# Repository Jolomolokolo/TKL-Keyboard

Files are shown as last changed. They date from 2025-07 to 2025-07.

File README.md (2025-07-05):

# TKL Keyboard – Custom Tenkeyless Mechanical Keyboard with Integrated RP2040

This project is a custom-designed TKL (Tenkeyless) mechanical keyboard with an ISO DE/QWERTZ layout. It features a fully hand-routed PCB with an onboard RP2040 microcontroller, integrated flash memory, reset and boot buttons, and support for hot-swap sockets.

---

## Project Overview

### Keyboard Overview  
This is an overview of the complete TKL keyboard project, including schematic, PCB, and case layout:

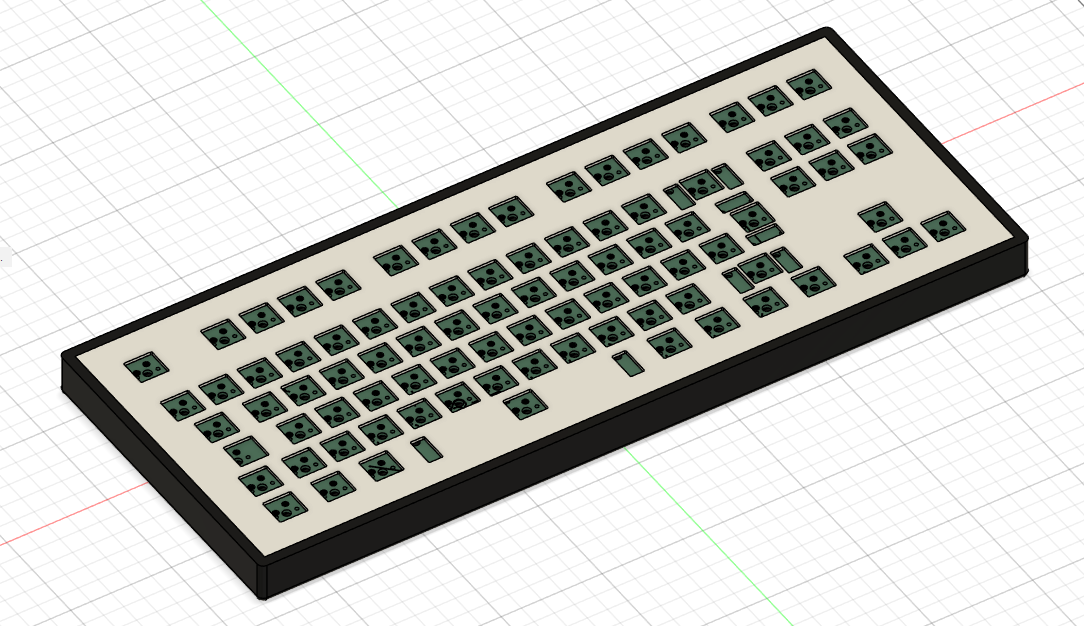
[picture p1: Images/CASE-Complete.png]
Keyboard Overview


---

### Schematic  
The keyboard uses a row-column matrix with diodes to prevent ghosting. The RP2040 is directly mounted on the PCB along with a crystal, power regulation, ESD protection, and SPI flash for firmware storage.

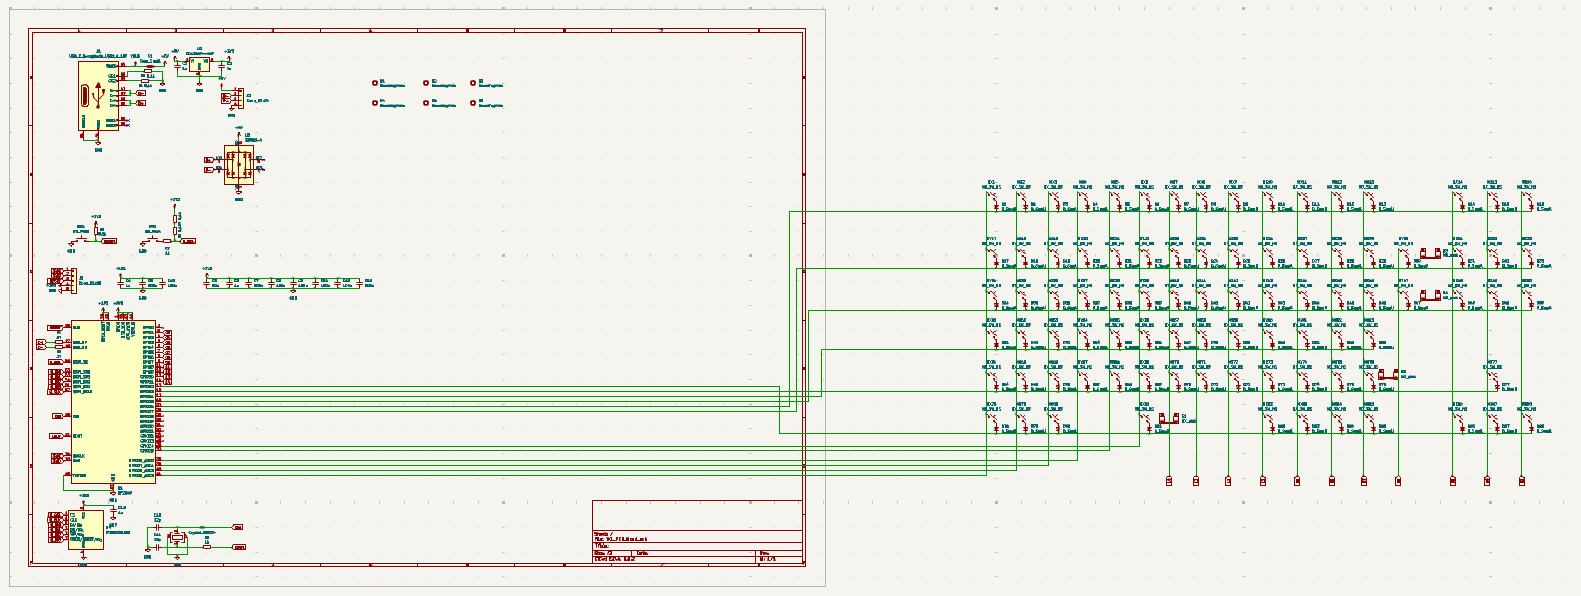
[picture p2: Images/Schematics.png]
Schematic


---

### PCB Layout  
The PCB is fully hand-routed and includes:

- RP2040 with external flash memory  
- USB-C port for programming and power  
- Boot and reset buttons  
- Crystal oscillator  
- Fuse for protection  
- Support for hot-swap switch sockets  
- ISO DE/QWERTZ-compliant layout  

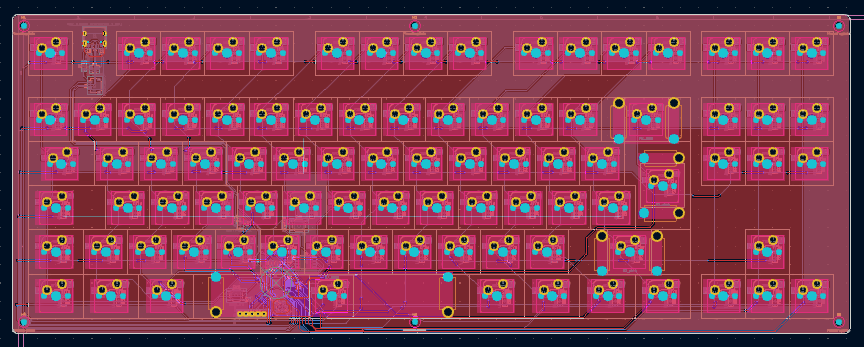
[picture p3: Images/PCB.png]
PCB Layout


---

### Case & Assembly  
The case uses standoffs, heated inserts, and screws to mount the PCB securely. Cutout for USB-C.
Compatible with standard MX keycaps and Cherry stabilizers.

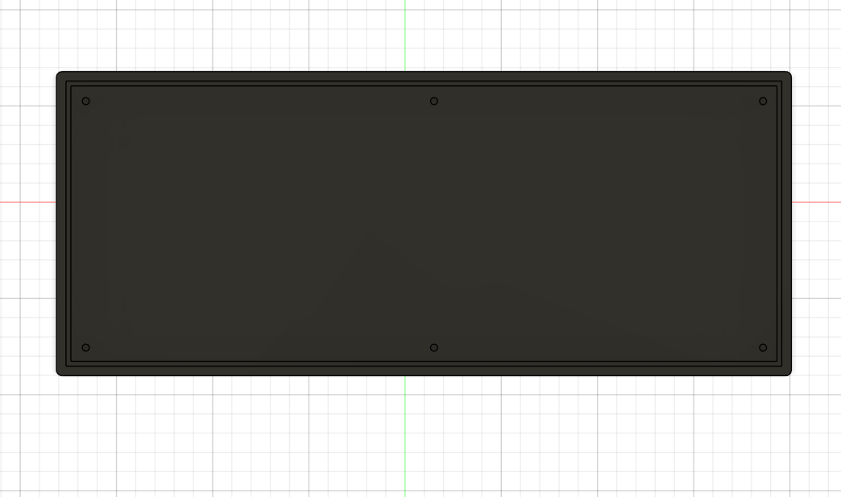
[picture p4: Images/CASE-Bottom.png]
Case Bottom with space for heated inserts

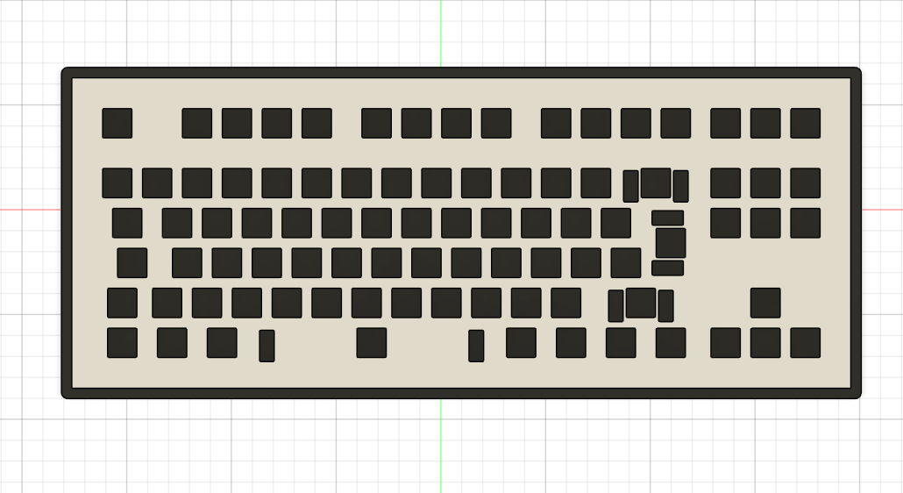
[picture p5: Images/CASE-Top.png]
Case


---

## Bill of Materials (BOM)

| Qty | Component | Value / Description | Footprint / Type |Price |
|-----|---|---|---|---|
| 8 | Capacitor | 100n | C_0402 |\/ |
| 5 | Capacitor | 1u | C_0402 |\/ |
| 2 | Capacitor | 22p | C_0402 |\/ |
| 1 | Capacitor | 10u | C_0603 |\/ |
| 5 | Resistor | 5.1k | R_0402 |\/ |
| 2 | Resistor | 27k | R_0402 |\/ |
| 2 | Resistor | 1k | R_0402 |\/ |
| 88  | Diodes | 1N4148 or equivalent (Ghosting Prevention) | SOD-123 |\/ |
| 1 | Microcontroller | RP2040 | QFN-56 |\/ |
| 1 | Voltage Regulator | XC6206PxxxMR | SOT-23-3 |\/ |
| 1 | ESD Protection | SRV05-4 | SOT-23-6 |\/ |
| 1 | Flash Memory | W25Q128JVS | SOIC-8 |\/ |
| 1 | Crystal | 12MHz / GND24 | SMD 3225-4Pin |\/ |
| 1 | Fuse | For USB protection | 1206 |\/ |
| 2 | Push Button | Reset / Boot | TL3342 |$128,97 |
| 88  | Hot-swap Sockets | MX-compatible | CPG151101S11 |$6,28 | 
| 4 | Stabilizers | 6.25u / 2.75u / 2u / ISO | Cherry MX |$11,77 |
| 1 | USB Port | USB-C 2.0 | 16P Receptacle |$2,01 |
| 1 | Debug Header | 4-pin JST | JST-SH 1.0mm |\/ |
| 1 | Debug Header | 5-pin Header | 2.54mm Vertical |$3,36 |
| 88  | Switches | Cherry MX or clone | MX-compatible |$61,24 |
| 88  | Keycaps | ISO DE Layout | Cherry Profile |$16,71 |
| 6 | Standoffs | 6×6mm M2.5 | Female-Male |$1,17 |
| 6 | Screws | M2.5×6mm | Steel |$1,78 |
| 6 | Heated Inserts | M2.5×6mm | Brass |$7,93 |
| 1 | USB Cable | USB-A to USB-C | — |- |
| | | | |Total: $241,22|

* "\/" means: Price is from a package/some parts are bought together and the price is under the arrow pointing down!
* Price is more than $150: I saw a $75 coupon for JLCPCB which would make the price a bit lower and the rest I would pay from my money!
---

## Firmware

The firmware is based on [KMK Firmware](https://github.com/KMKfw/kmk_firmware), a powerful Python-based keyboard firmware running on CircuitPython.

- Full matrix mapping (ISO DE layout)  
- Boot/reset control  
- Flash via USB, no external programmer required

Configuration is managed via `code.py` and `keymap.py`.

- Multi Layer Keyboard will be added!

---

## Future Improvements
 
- Add rotary encoder or OLED display  
- Bluetooth support (via BLE module)  
- Add underglow LED layer

---

## License

This project is open-source under the MIT License.

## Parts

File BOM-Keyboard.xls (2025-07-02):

Description | Category | References | Value | Footprint | Quantity | Total Quantity | Links | Price
Capacitor for USB and RP | PCB | C5, C7, C8, C9, C13, C14, C15, C16 | 100n | C_0402_1005Metric | 8 | 8 | PCB – JLCPCB | 128,97 Dollar
 |  | C1, C2, C4, C6, C12 | 1u | C_0402_1005Metric | 5 | 5
 |  | C10, C11 | 22p | C_0402_1005Metric | 2 | 2
 |  | C3 | 10u | C_0603_1608Metric | 1 | 1
Resistor for USB and RP |  | R1, R2, R3, R8, R9 | 5,1k | R_0402_1005Metric | 5 | 5
 |  | R4, R5 | 27k | R_0402_1005Metric | 2 | 2
 |  | R6, R7 | 1k | R_0402_1005Metric | 2 | 2
Diodes for Ghosting Prevention |  | D1, D2, D3, D4, D5, D6, D7, D8, D9, D10, D11, D12, D13, D14, D15, D16, D17, D18, D19, D20, D21, D22, D23, D24, D25, D26, D27, D28, D29, D30, D31, D32, D33, D34, D35, D36, D37, D38, D39, D40, D41, D42, D43, D44, D45, D46, D47, D48, D49, D50, D51, D52, D53, D54, D55, D56, D57, D58, D59, D60, D61, D62, D63, D64, D65, D66, D67, D68, D69, D70, D71, D72, D73, D74, D75, D76, D77, D78, D79, D80, D81, D82, D83, D84, D85, D86, D87, D88 | D_Small | D_SOD-123 | 88 | 88
Micro Controller |  | U1 | RP2040 | QFN-56-1EP_7x7mm_P0.4mm_EP3.2x3.2mm | 1 | 1
MISC: Flash Memory and stuff like that |  | U2 | XC6206PxxxMR | SOT-23-3 | 1 | 1
 |  | U3 | SRV05-4 | SOT-23-6-routable | 1 | 1
 |  | U4 | W25Q128JVS | SOIC-8_5.3x5.3mm_P1.27mm | 1 | 1
Crystal for Timing |  | Y1 | Crystal_GND24 | Crystal_SMD_3225-4Pin_3.2x2.5mm | 1 | 1
Fuse for safety |  | F1 | Fuse_Small | Fuse_1206_3216Metric | 1 | 1
Push Buttons for Reset and Flash-Reset |  | SW1, SW2 | SW_Push | SW_SPST_TL3342 | 2 | 2
Kalith Hot-Swap mountings |  | MX1, MX2, MX3, MX4, MX5, MX6, MX7, MX8, MX9, MX10, MX11, MX12, MX13, MX14, MX15, MX16, MX17, MX18, MX19, MX20, MX21, MX22, MX23, MX24, MX25, MX26, MX27, MX28, MX29, MX30, MX31, MX32, MX33, MX35, MX36, MX37, MX38, MX39, MX40, MX41, MX42, MX43, MX44, MX45, MX46, MX47, MX48, MX49, MX50, MX52, MX53, MX54, MX55, MX56, MX57, MX58, MX59, MX60, MX61, MX62, MX63, MX65, MX66, MX67, MX68, MX69, MX70, MX71, MX72, MX73, MX74, MX75, MX76, MX77, MX81, MX86, MX87, MX88 | MX_SW_HS | SW_MX_HS_CPG151101S11_1u | 78 | 88 | https://www.aliexpress.com/ssr/300000512/BundleDeals2?productIds=1005008078624472:12000043571615166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 | 5.33 €
 |  | MX64, MX78, MX79, MX80, MX82, MX83, MX84, MX85 | MX_SW_HS | SW_MX_HS_CPG151101S11_1.25u | 8
 |  | MX34 | MX_SW_HS | SW_MX_HS_CPG151101S11_1.5u | 1
 |  | MX51 | MX_SW_HS | SW_MX_HS_CPG151101S11_1.75u_STP_1.25 | 1
Stabilizer for bigger Keys |  | S1 | MX_stab | STAB_MX_P_6.25u | 1 | 1 – SET | https://www.computerxtreme.de/Glorious-Stabilizers-V2?gh=2 | 9.99 €
 |  | S2 | MX_stab | STAB_MX_P_2.75u | 1
 |  | S3 | MX_stab | STAB_MX_P_2u | 1
 |  | S4 | MX_stab | STAB_MX_P_ISO-ROT | 1
USB-C 2.0 Port |  | J1 | USB_C_Receptacle_USB2.0_16P | USB_C_Receptacle_HRO_TYPE-C-31-M-12 | 1 | 1 | https://de.aliexpress.com/item/1005003285152827.html | 1.71 €
Pin Header for Debug |  | J2 | Conn_01x04 | JST_SH_SM04B-SRSS-TB_1x04-1MP_P1.00mm_Horizontal | 1 | 1 | https://de.aliexpress.com/item/1005006498660940.html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 | 2.85 €
 |  | J3 | Conn_01x05 | PinHeader_1x05_P2.54mm_Vertical | 1 | 1
Keys for Keyboard | Keys |  | Cherry MX Keys | Cherry MX Keys | 88 | 88 | https://www.reichelt.de/de/de/shop/produkt/cherry_mx_red_rgb_-_tastenmodul-401645 | 52.00 €
Keycaps for Keyboard |  |  | Cherry MX Keycaps | Cherry MX Keycaps, different sizes | 88 | 1-SET | https://de.aliexpress.com/item/4001297074837.html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 | 14.19 €
Standoffs for PCB-Mounting | Case/Mounting |  | Standoff 6mmx6mm – M2,5 | Standoffs 6mmx6mm – female-male | 6 | 6 | https://de.aliexpress.com/item/1005006202979514.html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 | 0.99 €
Screws for PCB-Mounting |  |  | Screws M2,5mmx6mm | Screws M2,5mmx6mm | 6 | 6 | https://de.aliexpress.com/item/1005002357962115.html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 | 1.51 €
Heated inserts for PCB-Mounting |  |  | Heated inserts for M2,5x6mm | M2,5mmxL6mmxD3,5mm | 6 | 6 | https://de.aliexpress.com/item/1005007830491580.html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 | 6.73 € | 95.30 €
Programming | Others |  | USB-A to USB-C | USB-A to USB-C | 1 | 1
 |  |  |  |  |  |  |  | Total in USD
 |  |  |  |  |  |  |  | PCB | $128.97
 |  |  |  |  |  |  |  | Parts | $112.47
 |  |  |  |  |  |  |  |  | $241.44

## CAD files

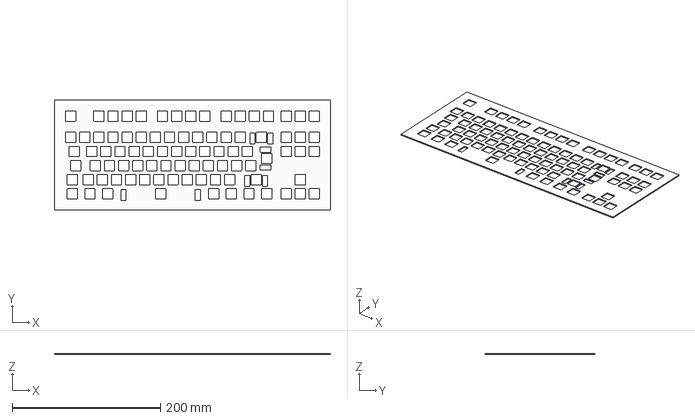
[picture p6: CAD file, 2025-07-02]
CAD/TKL-Keyboard-Top.step
371.9 x 148.1 x 1.50 mm

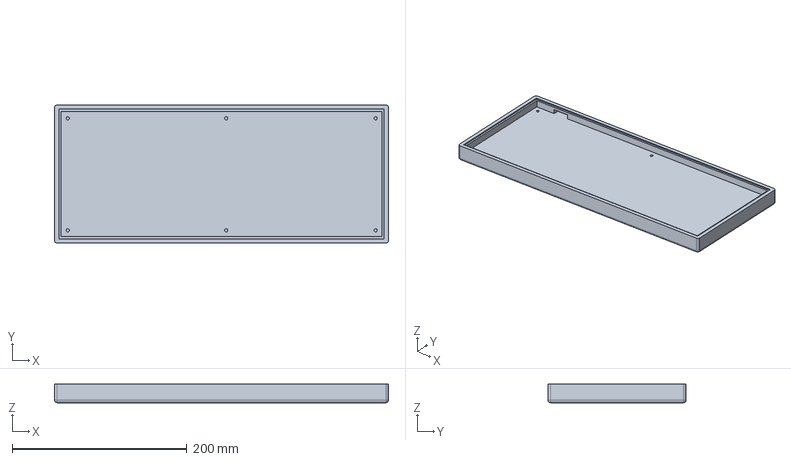
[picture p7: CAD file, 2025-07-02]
CAD/TKL-Keyboard-Bottom.step
381.9 x 158.1 x 21.2 mm

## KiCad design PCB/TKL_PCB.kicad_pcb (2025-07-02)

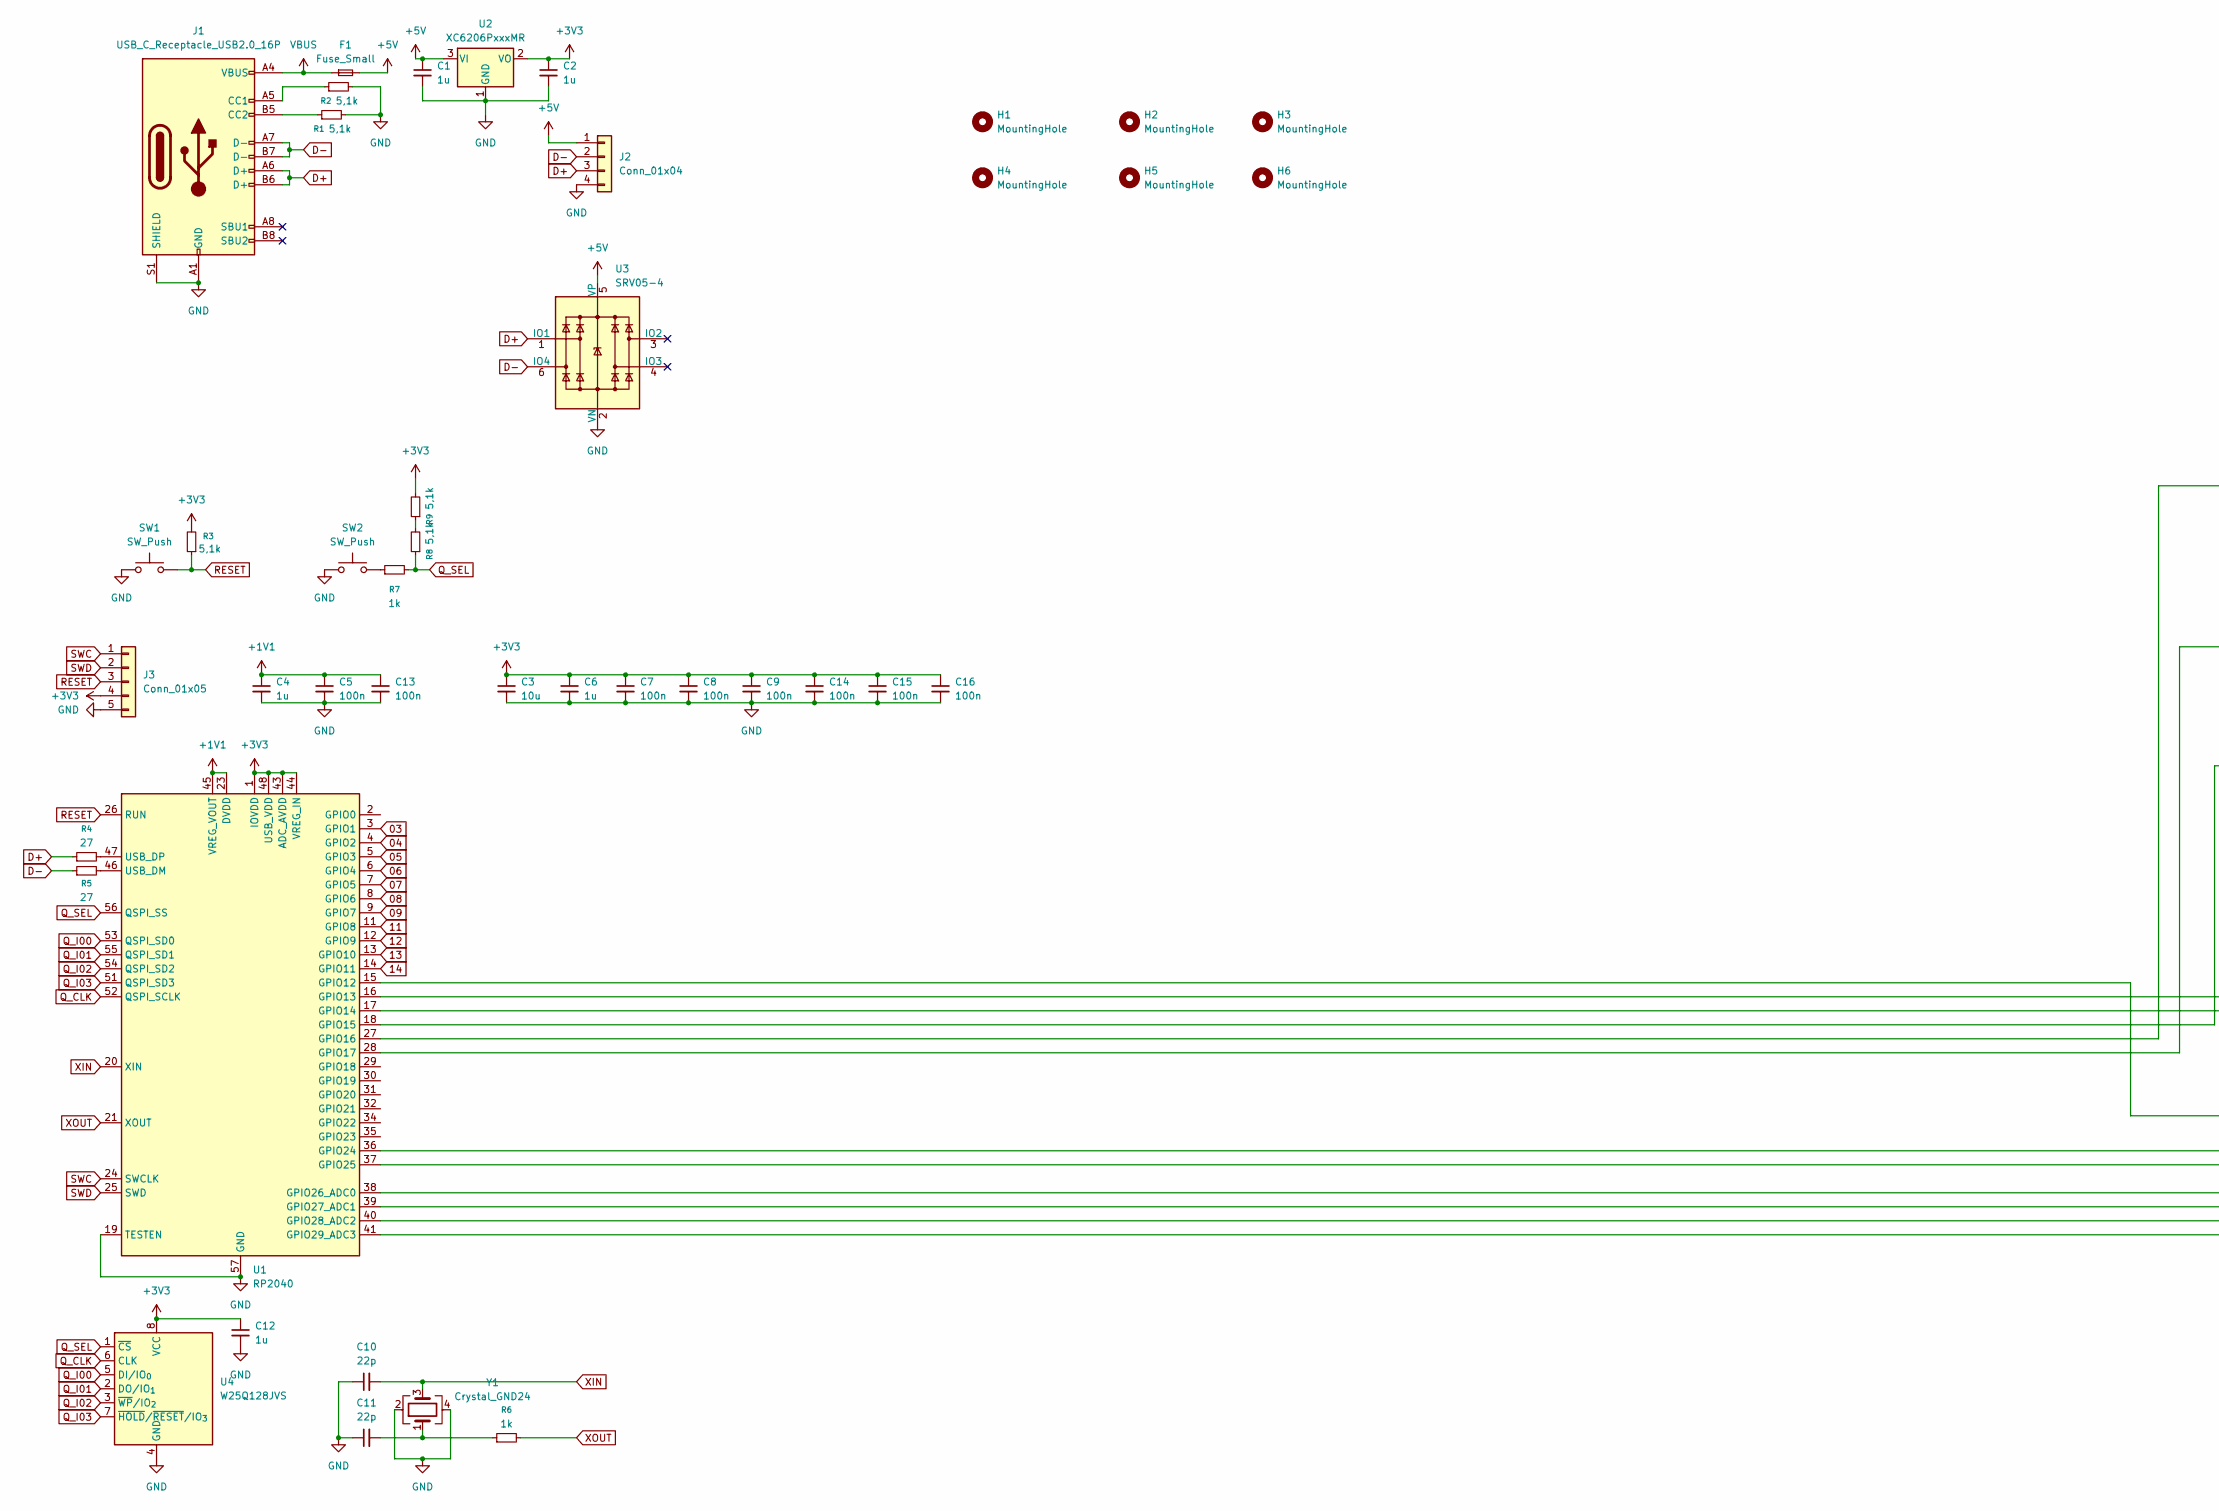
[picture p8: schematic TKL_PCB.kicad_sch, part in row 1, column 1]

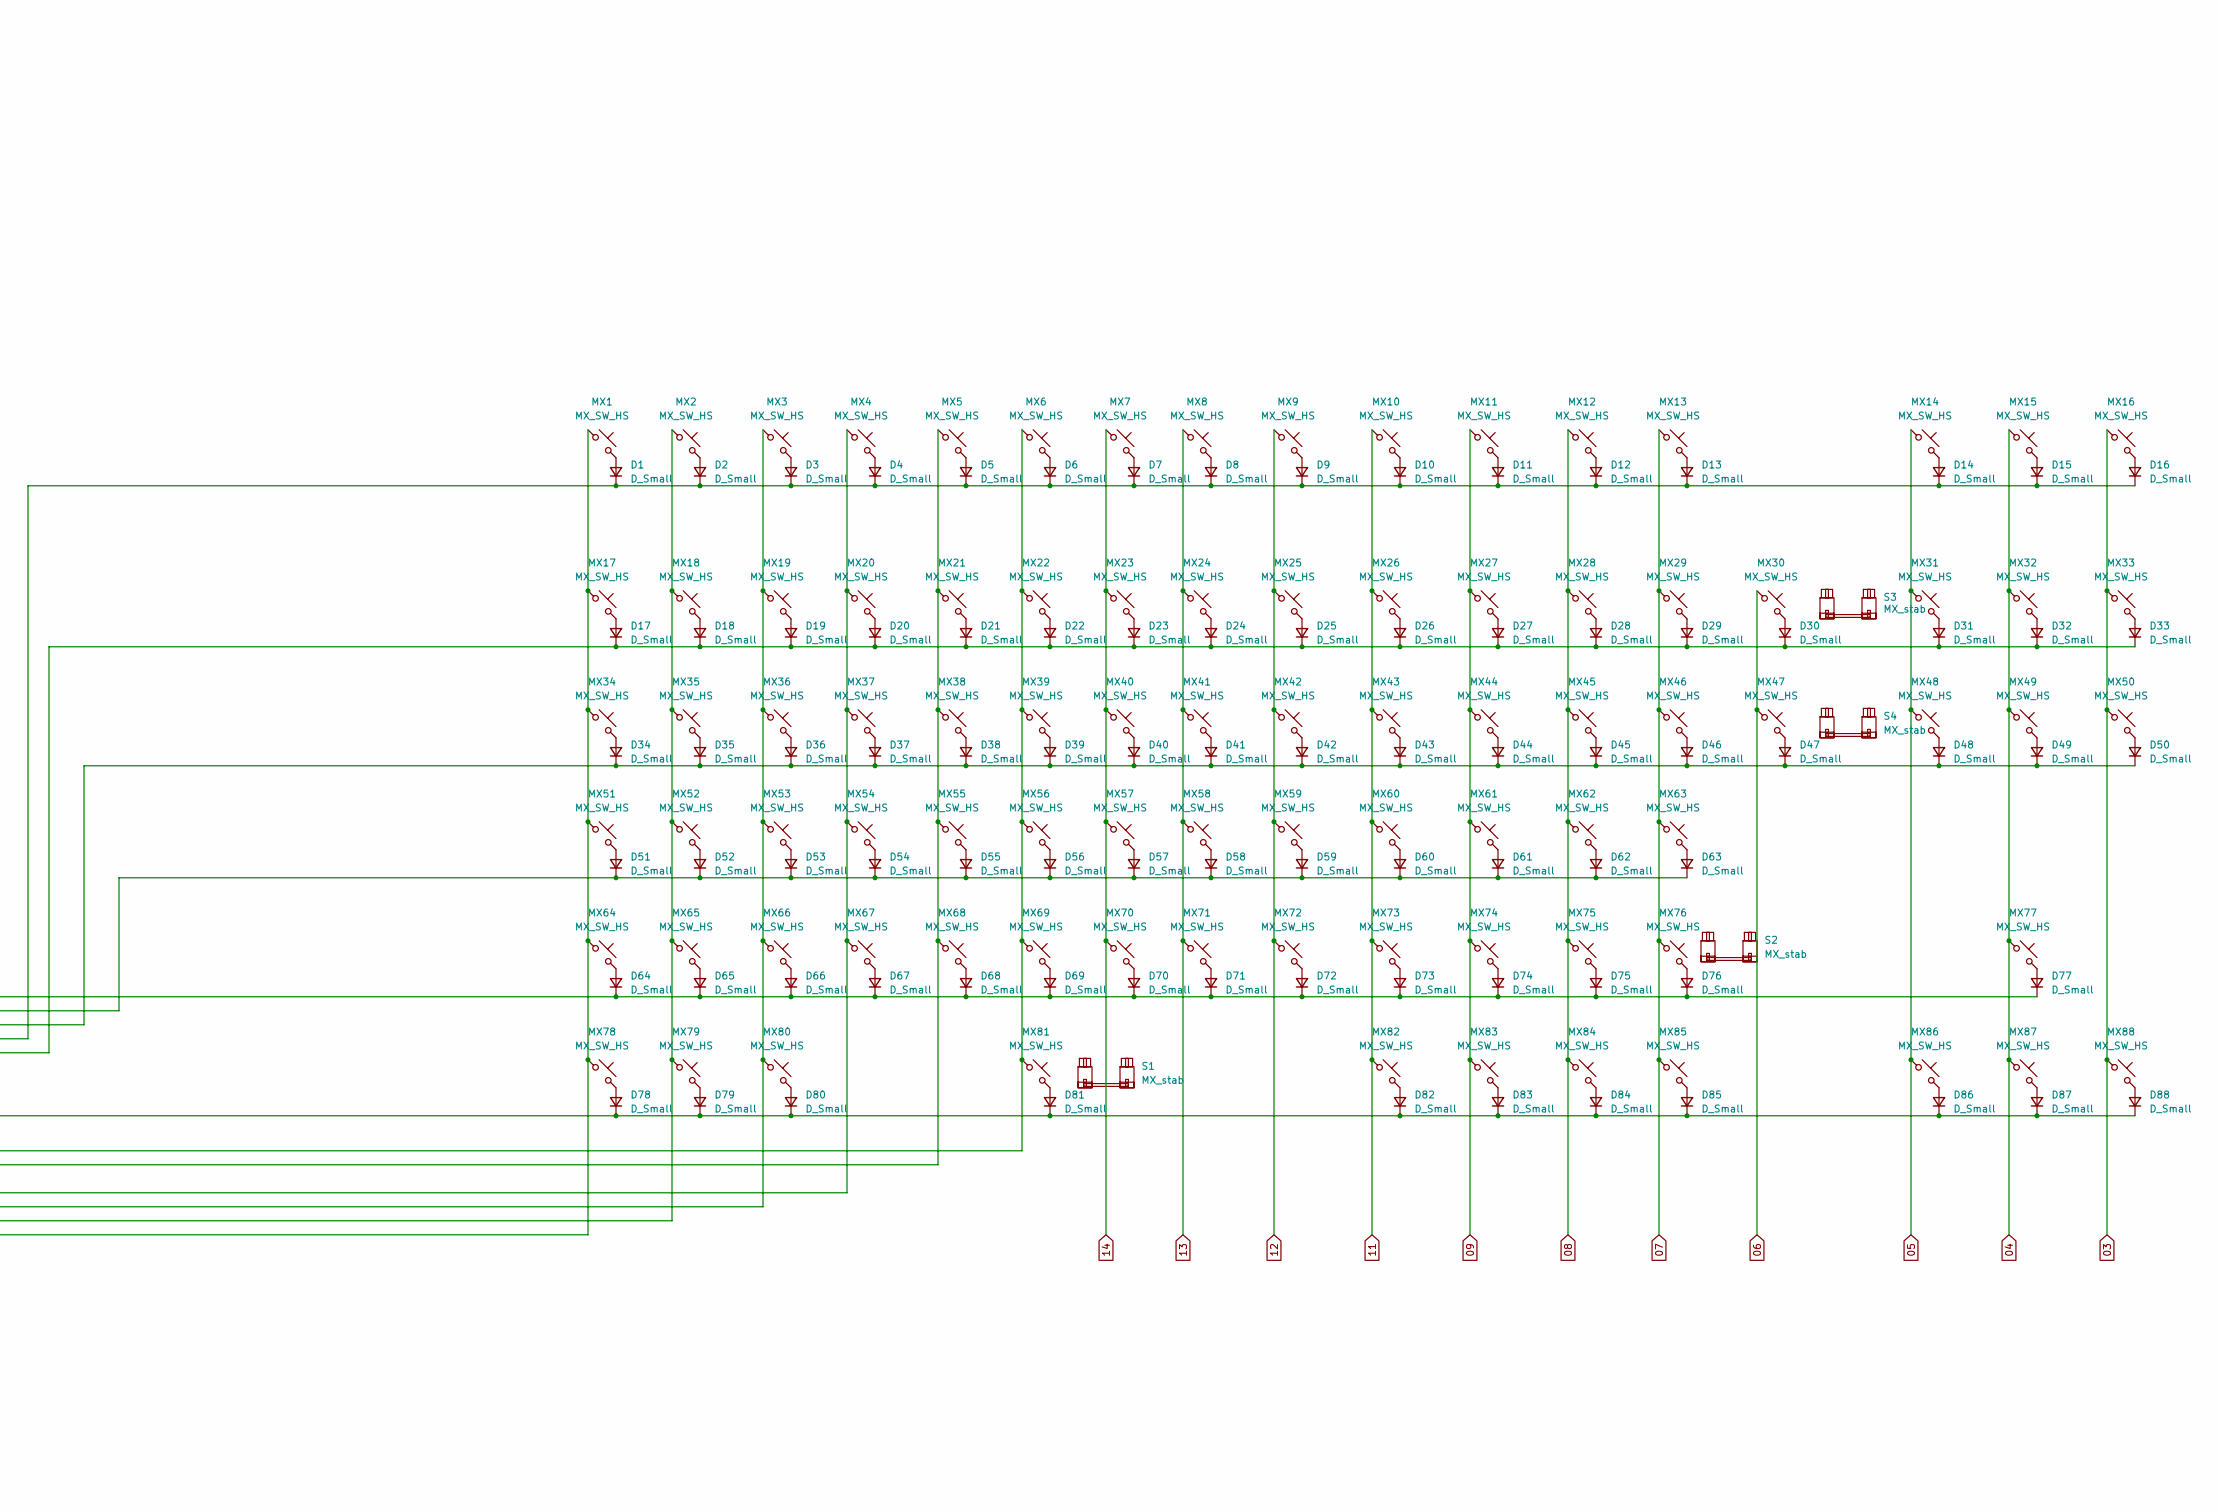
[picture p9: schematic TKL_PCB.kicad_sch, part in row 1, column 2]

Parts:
C1, C2, C4, C6, C12: 1u; C_0402_1005Metric
C3: 10u; C_0603_1608Metric
C5, C7, C8, C9, C13, C14, C15, C16: 100n; C_0402_1005Metric
C10, C11: 22p; C_0402_1005Metric
D1, D2, D3, D4, D5, D6, D7, D8, D9, D10, D11, D12, D13, D14, D15, D16, D17, D18, D19, D20, D21, D22, D23, D24, D25, D26, D27, D28, D29, D30, D31, D32, D33, D34, D35, D36, D37, D38, D39, D40, D41, D42, D43, D44, D45, D46, D47, D48, D49, D50, D51, D52, D53, D54, D55, D56, D57, D58, D59, D60, D61, D62, D63, D64, D65, D66, D67, D68, D69, D70, D71, D72, D73, D74, D75, D76, D77, D78, D79, D80, D81, D82, D83, D84, D85, D86, D87, D88: D_Small; D_SOD-123
F1: Fuse_Small; Fuse_1206_3216Metric
H1, H2, H3, H4, H5, H6: MountingHole; MountingHole_2.5mm
J1: USB_C_Receptacle_USB2.0_16P; USB_C_Receptacle_HRO_TYPE-C-31-M-12
J2: Conn_01x04; JST_SH_SM04B-SRSS-TB_1x04-1MP_P1.00mm_Horizontal
J3: Conn_01x05; PinHeader_1x05_P2.54mm_Vertical
MX1, MX2, MX3, MX4, MX5, MX6, MX7, MX8, MX9, MX10, MX11, MX12, MX13, MX14, MX15, MX16, MX17, MX18, MX19, MX20, MX21, MX22, MX23, MX24, MX25, MX26, MX27, MX28, MX29, MX30, MX31, MX32, MX33, MX35, MX36, MX37, MX38, MX39, MX40, MX41, MX42, MX43, MX44, MX45, MX46, MX47, MX48, MX49, MX50, MX52, MX53, MX54, MX55, MX56, MX57, MX58, MX59, MX60, MX61, MX62, MX63, MX65, MX66, MX67, MX68, MX69, MX70, MX71, MX72, MX73, MX74, MX75, MX76, MX77, MX81, MX86, MX87, MX88: MX_SW_HS; SW_MX_HS_CPG151101S11_1u
MX34: MX_SW_HS; SW_MX_HS_CPG151101S11_1.5u
MX51: MX_SW_HS; SW_MX_HS_CPG151101S11_1.75u_STP_1.25
MX64, MX78, MX79, MX80, MX82, MX83, MX84, MX85: MX_SW_HS; SW_MX_HS_CPG151101S11_1.25u
R1, R2, R3, R8, R9: 5,1k; R_0402_1005Metric
R4, R5: 27; R_0402_1005Metric
R6, R7: 1k; R_0402_1005Metric
S1: MX_stab; STAB_MX_P_6.25u
S2: MX_stab; STAB_MX_P_2.75u
S3: MX_stab; STAB_MX_P_2u
S4: MX_stab; STAB_MX_P_ISO-ROT
SW1, SW2: SW_Push; SW_SPST_TL3342
U1: RP2040; QFN-56-1EP_7x7mm_P0.4mm_EP3.2x3.2mm
U2: XC6206PxxxMR; SOT-23-3
U3: SRV05-4; SOT-23-6-routable
U4: W25Q128JVS; SOIC-8_5.3x5.3mm_P1.27mm
Y1: Crystal_GND24; Crystal_SMD_3225-4Pin_3.2x2.5mm

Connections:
03: MX16.1, MX33.1, MX50.1, MX88.1, U1.3 (GPIO1)
04: MX15.1, MX32.1, MX49.1, MX77.1, MX87.1, U1.4 (GPIO2)
05: MX14.1, MX31.1, MX48.1, MX86.1, U1.5 (GPIO3)
06: MX30.1, MX47.1, U1.6 (GPIO4)
07: MX13.1, MX29.1, MX46.1, MX63.1, MX76.1, MX85.1, U1.7 (GPIO5)
08: MX12.1, MX28.1, MX45.1, MX62.1, MX75.1, MX84.1, U1.8 (GPIO6)
09: MX11.1, MX27.1, MX44.1, MX61.1, MX74.1, MX83.1, U1.9 (GPIO7)
11: MX10.1, MX26.1, MX43.1, MX60.1, MX73.1, MX82.1, U1.11 (GPIO8)
12: MX9.1, MX25.1, MX42.1, MX59.1, MX72.1, U1.12 (GPIO9)
13: MX8.1, MX24.1, MX41.1, MX58.1, MX71.1, U1.13 (GPIO10)
14: MX7.1, MX23.1, MX40.1, MX57.1, MX70.1, U1.14 (GPIO11)
+1V1: C4.1, C5.1, C13.1, U1.23 (DVDD), U1.45 (VREG_VOUT), U1.50 (DVDD)
+3V3: C2.1, C3.1, C6.1, C7.1, C8.1, C9.1, C12.1, C14.1, C15.1, C16.1, J3.4, R3.2, R9.2, U1.1 (IOVDD), U1.10 (IOVDD), U1.22 (IOVDD), U1.33 (IOVDD), U1.42 (IOVDD), U1.43 (ADC_AVDD), U1.44 (VREG_IN), U1.48 (USB_VDD), U1.49 (IOVDD), U2.2 (VO), U4.8 (VCC)
+5V: C1.1, F1.2, J2.1, U2.3 (VI), U3.5 (VP)
D+: J1.A6 (D+), J1.B6 (D+), J2.3, R4.1, U3.1 (IO1)
D-: J1.A7 (D-), J1.B7 (D-), J2.2, R5.1, U3.6 (IO4)
GND: C1.2, C2.2, C3.2, C4.2, C5.2, C6.2, C7.2, C8.2, C9.2, C10.1, C11.1, C12.2, C13.2, C14.2, C15.2, C16.2, J1.A1 (GND), J1.A12 (GND), J1.B1 (GND), J1.B12 (GND), J1.S1 (SHIELD), J2.4, J3.5, R1.2, R2.2, SW1.1, SW2.1, U1.19 (TESTEN), U1.57 (GND), U2.1 (GND), U3.2 (VN), U4.4 (GND), Y1.2, Y1.4
unnamed: C11.2, R6.1, Y1.1
unnamed: D1.2 (A), MX1.2
unnamed: D1.1 (K), D2.1 (K), D3.1 (K), D4.1 (K), D5.1 (K), D6.1 (K), D7.1 (K), D8.1 (K), D9.1 (K), D10.1 (K), D11.1 (K), D12.1 (K), D13.1 (K), D14.1 (K), D15.1 (K), D16.1 (K), U1.27 (GPIO16)
unnamed: D2.2 (A), MX2.2
unnamed: D3.2 (A), MX3.2
unnamed: D4.2 (A), MX4.2
unnamed: D5.2 (A), MX5.2
unnamed: D6.2 (A), MX6.2
unnamed: D7.2 (A), MX7.2
unnamed: D8.2 (A), MX8.2
unnamed: D9.2 (A), MX9.2
unnamed: D10.2 (A), MX10.2
unnamed: D11.2 (A), MX11.2
unnamed: D12.2 (A), MX12.2
unnamed: D13.2 (A), MX13.2
unnamed: D14.2 (A), MX14.2
unnamed: D15.2 (A), MX15.2
unnamed: D16.2 (A), MX16.2
unnamed: D17.2 (A), MX17.2
unnamed: D17.1 (K), D18.1 (K), D19.1 (K), D20.1 (K), D21.1 (K), D22.1 (K), D23.1 (K), D24.1 (K), D25.1 (K), D26.1 (K), D27.1 (K), D28.1 (K), D29.1 (K), D30.1 (K), D31.1 (K), D32.1 (K), D33.1 (K), U1.28 (GPIO17)
unnamed: D18.2 (A), MX18.2
unnamed: D19.2 (A), MX19.2
unnamed: D20.2 (A), MX20.2
unnamed: D21.2 (A), MX21.2
unnamed: D22.2 (A), MX22.2
unnamed: D23.2 (A), MX23.2
unnamed: D24.2 (A), MX24.2
unnamed: D25.2 (A), MX25.2
unnamed: D26.2 (A), MX26.2
unnamed: D27.2 (A), MX27.2
unnamed: D28.2 (A), MX28.2
unnamed: D29.2 (A), MX29.2
unnamed: D30.2 (A), MX30.2
unnamed: D31.2 (A), MX31.2
unnamed: D32.2 (A), MX32.2
unnamed: D33.2 (A), MX33.2
unnamed: D34.2 (A), MX34.2
unnamed: D34.1 (K), D35.1 (K), D36.1 (K), D37.1 (K), D38.1 (K), D39.1 (K), D40.1 (K), D41.1 (K), D42.1 (K), D43.1 (K), D44.1 (K), D45.1 (K), D46.1 (K), D47.1 (K), D48.1 (K), D49.1 (K), D50.1 (K), U1.18 (GPIO15)
unnamed: D35.2 (A), MX35.2
unnamed: D36.2 (A), MX36.2
unnamed: D37.2 (A), MX37.2
unnamed: D38.2 (A), MX38.2
unnamed: D39.2 (A), MX39.2
unnamed: D40.2 (A), MX40.2
unnamed: D41.2 (A), MX41.2
unnamed: D42.2 (A), MX42.2
unnamed: D43.2 (A), MX43.2
unnamed: D44.2 (A), MX44.2
unnamed: D45.2 (A), MX45.2
unnamed: D46.2 (A), MX46.2
unnamed: D47.2 (A), MX47.2
unnamed: D48.2 (A), MX48.2
unnamed: D49.2 (A), MX49.2
unnamed: D50.2 (A), MX50.2
unnamed: D51.2 (A), MX51.2
unnamed: D51.1 (K), D52.1 (K), D53.1 (K), D54.1 (K), D55.1 (K), D56.1 (K), D57.1 (K), D58.1 (K), D59.1 (K), D60.1 (K), D61.1 (K), D62.1 (K), D63.1 (K), U1.17 (GPIO14)
unnamed: D52.2 (A), MX52.2
unnamed: D53.2 (A), MX53.2
unnamed: D54.2 (A), MX54.2
unnamed: D55.2 (A), MX55.2
unnamed: D56.2 (A), MX56.2
unnamed: D57.2 (A), MX57.2
unnamed: D58.2 (A), MX58.2
unnamed: D59.2 (A), MX59.2
unnamed: D60.2 (A), MX60.2
unnamed: D61.2 (A), MX61.2
unnamed: D62.2 (A), MX62.2
unnamed: D63.2 (A), MX63.2
unnamed: D64.2 (A), MX64.2
unnamed: D64.1 (K), D65.1 (K), D66.1 (K), D67.1 (K), D68.1 (K), D69.1 (K), D70.1 (K), D71.1 (K), D72.1 (K), D73.1 (K), D74.1 (K), D75.1 (K), D76.1 (K), D77.1 (K), U1.16 (GPIO13)
unnamed: D65.2 (A), MX65.2
unnamed: D66.2 (A), MX66.2
unnamed: D67.2 (A), MX67.2
unnamed: D68.2 (A), MX68.2
unnamed: D69.2 (A), MX69.2
unnamed: D70.2 (A), MX70.2
unnamed: D71.2 (A), MX71.2
unnamed: D72.2 (A), MX72.2
unnamed: D73.2 (A), MX73.2
unnamed: D74.2 (A), MX74.2
unnamed: D75.2 (A), MX75.2
unnamed: D76.2 (A), MX76.2
unnamed: D77.2 (A), MX77.2
unnamed: D78.2 (A), MX78.2
unnamed: D78.1 (K), D79.1 (K), D80.1 (K), D81.1 (K), D82.1 (K), D83.1 (K), D84.1 (K), D85.1 (K), D86.1 (K), D87.1 (K), D88.1 (K), U1.15 (GPIO12)
unnamed: D79.2 (A), MX79.2
unnamed: D80.2 (A), MX80.2
unnamed: D81.2 (A), MX81.2
unnamed: D82.2 (A), MX82.2
unnamed: D83.2 (A), MX83.2
unnamed: D84.2 (A), MX84.2
unnamed: D85.2 (A), MX85.2
unnamed: D86.2 (A), MX86.2
unnamed: D87.2 (A), MX87.2
unnamed: D88.2 (A), MX88.2
unnamed: J1.A5 (CC1), R2.1
unnamed: J1.B5 (CC2), R1.1
unnamed: R7.1, SW2.2
unnamed: R8.2, R9.1
unnamed: MX6.1, MX22.1, MX39.1, MX56.1, MX69.1, MX81.1, U1.36 (GPIO24)
unnamed: MX5.1, MX21.1, MX38.1, MX55.1, MX68.1, U1.37 (GPIO25)
unnamed: MX4.1, MX20.1, MX37.1, MX54.1, MX67.1, U1.38 (GPIO26_ADC0)
unnamed: MX3.1, MX19.1, MX36.1, MX53.1, MX66.1, MX80.1, U1.39 (GPIO27_ADC1)
unnamed: MX2.1, MX18.1, MX35.1, MX52.1, MX65.1, MX79.1, U1.40 (GPIO28_ADC2)
unnamed: MX1.1, MX17.1, MX34.1, MX51.1, MX64.1, MX78.1, U1.41 (GPIO29_ADC3)
unnamed: R5.2, U1.46 (USB_DM)
unnamed: R4.2, U1.47 (USB_DP)
Q_CLK: U1.52 (QSPI_SCLK), U4.6 (CLK)
Q_I00: U1.53 (QSPI_SD0), U4.5 (DI/IO_{0})
Q_I01: U1.55 (QSPI_SD1), U4.2 (DO/IO_{1})
Q_I02: U1.54 (QSPI_SD2), U4.3 (~WP/IO_{2})
Q_I03: U1.51 (QSPI_SD3), U4.7 (~HOLD/~RESET/IO_{3})
Q_SEL: R7.2, R8.1, U1.56 (QSPI_SS), U4.1 (~CS)
RESET: J3.3, R3.1, SW1.2, U1.26 (RUN)
SWC: J3.1, U1.24 (SWCLK)
SWD: J3.2, U1.25 (SWD)
VBUS: F1.1, J1.A4 (VBUS), J1.A9 (VBUS), J1.B4 (VBUS), J1.B9 (VBUS)
XIN: C10.2, U1.20 (XIN), Y1.3
XOUT: R6.2, U1.21 (XOUT)

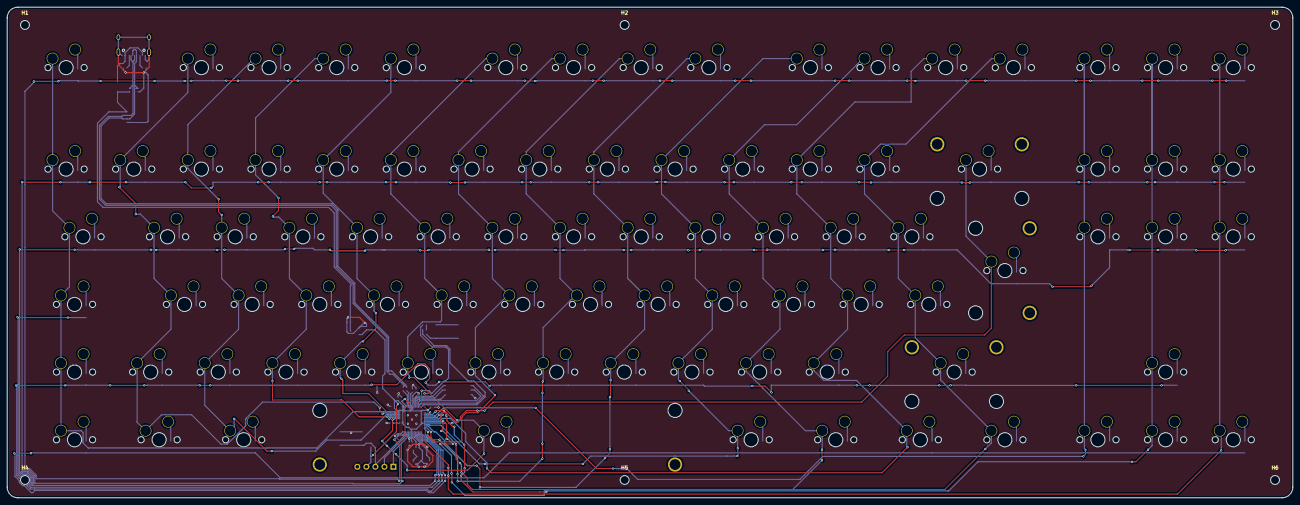
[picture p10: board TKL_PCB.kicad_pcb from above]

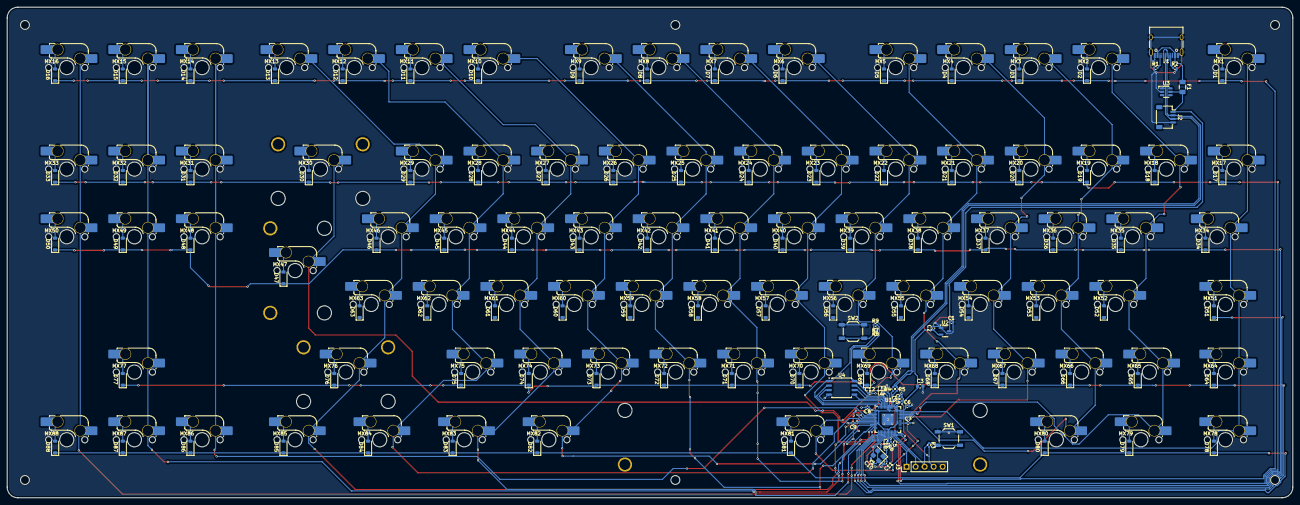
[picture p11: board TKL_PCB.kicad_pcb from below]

Board: 2 copper layers, 361.9 x 138.1 mm, 222 parts (212 on the bottom side), 136 nets.

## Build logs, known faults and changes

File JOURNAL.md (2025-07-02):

# Journal for the TKL-Keyboard by Jolomolokolo

**Information:**

- title: Jolomolokolo-TKL-ISO-DE  
- author: Jolomolokolo  
- description: Tenkeyless mechanical keyboard with ISO-DE (QWERTZ) layout, custom hand-routed PCB with RP2040, flash memory, and reset buttons.  
- created at: 2025-06-23  

**Total time spent: ~ 37 hours**

---

## 2025-06-23

- Researched TKL and ISO-DE layouts  
- Planned custom PCB with onboard RP2040  
- Started schematic and selected components  

Time: ~ 5 hours

---

## 2025-06-24

- Researched about KiCAD/found Software for the placing of a Layout from a JSON-File
- Installed and tried it out 

Time: ~ 2 hours

---

## 2025-06-25

- Continued schematic work in KiCad  
- Finished and DRC-Checked and some last research for safety
- Added Fuse to USB-C Connection

Time: ~ 6 hours

---

## 2025-06-27

- Routed PCB by hand  
- Adjusted placement for signal integrity  
- Completed design rule checks (DRC)  

Time: ~ 5 hours

---

## 2025-06-29

- Designed keyboard case in CAD  
- Aligned USB port and mounting holes
- Researched and added the heated inserts/the holes
- Added mounting holes to the PCB
- More polishing  

Time: ~ 8 hours

---

## 2025-06-30

- Finalized PCB silkscreen    
- Exported Gerber and drill files
- Made Place-File and BOM from PCB

Time: ~ 3 hours

---

## 2025-06-31

- Checked parts list and footprints  
- Created draft README and documentation
- Created BOM

Time: ~ 4 hours

---

## 2025-07-02

- Started and finished with firmware with KMK  
- Defined pins and keymap

Time: ~ 4 hours

---

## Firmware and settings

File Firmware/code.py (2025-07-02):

from kmk.kmk_keyboard import KMKKeyboard
from kmk.keys import KC
from kmk.scanners import DiodeOrientation

keyboard = KMKKeyboard()

# Define your row and column pins — update these for your actual PCB!
keyboard.col_pins = (26, 27, 28, 29, 6, 7, 8, 9, 10, 11, 12, 13, 14, 15)  # 14 columns (example)
keyboard.row_pins = (0, 1, 2, 3, 4, 5)  # 6 rows (example)

keyboard.diode_orientation = DiodeOrientation.COL2ROW

from keymap import layers
keyboard.keymap = layers

if __name__ == '__main__':
    keyboard.go()

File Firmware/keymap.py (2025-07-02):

from kmk.keys import KC

layers = [
    [
        KC.ESC,    KC._1,     KC._2,     KC._3,     KC._4,     KC._5,     KC._6,     KC._7,     KC._8,     KC._9,     KC._0,     KC.MINS,   KC.EQL,    KC.BSPC,
        KC.TAB,    KC.Q,      KC.W,      KC.E,      KC.R,      KC.T,      KC.Y,      KC.U,      KC.I,      KC.O,      KC.P,      KC.LBRC,   KC.RBRC,   KC.BSLS,
        KC.CAPS,   KC.A,      KC.S,      KC.D,      KC.F,      KC.G,      KC.H,      KC.J,      KC.K,      KC.L,      KC.SCLN,   KC.QUOT,   KC.ENTER,
        KC.LSFT,   KC.NUBS,   KC.Z,      KC.X,      KC.C,      KC.V,      KC.B,      KC.N,      KC.M,      KC.COMM,   KC.DOT,    KC.SLSH,   KC.RSFT,
        KC.LCTL,   KC.LGUI,   KC.LALT,   KC.SPC,    KC.RALT,   KC.RGUI,   KC.APP,    KC.RCTL
    ]
]

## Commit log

2025-07-02 Add initial firmware and expand project documentation
    Added boot.py, code.py, and keymap.py to provide initial CircuitPython/KMK firmware for the custom TKL keyboard. Updated README.md with detailed project overview, schematic, PCB layout, case assembly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
2025-07-05 Added prices to BOM
